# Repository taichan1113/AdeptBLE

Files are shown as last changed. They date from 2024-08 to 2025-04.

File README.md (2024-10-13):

# Excuse

This is alpha version of Ploopy Adept BLE modification.

All necessary files are here but they are still messy.

Document may not reach your satisfaction.

## electronics

Designed by KiCAD and produted by [JLCPCB](https://jlcpcb.com/)

Basically you need XIAO nRF52840 board, PMW3610 optical sensor, omron D2LS-21 mouse switch, 6-pin slide switch and battery.

Other parts are set as below.

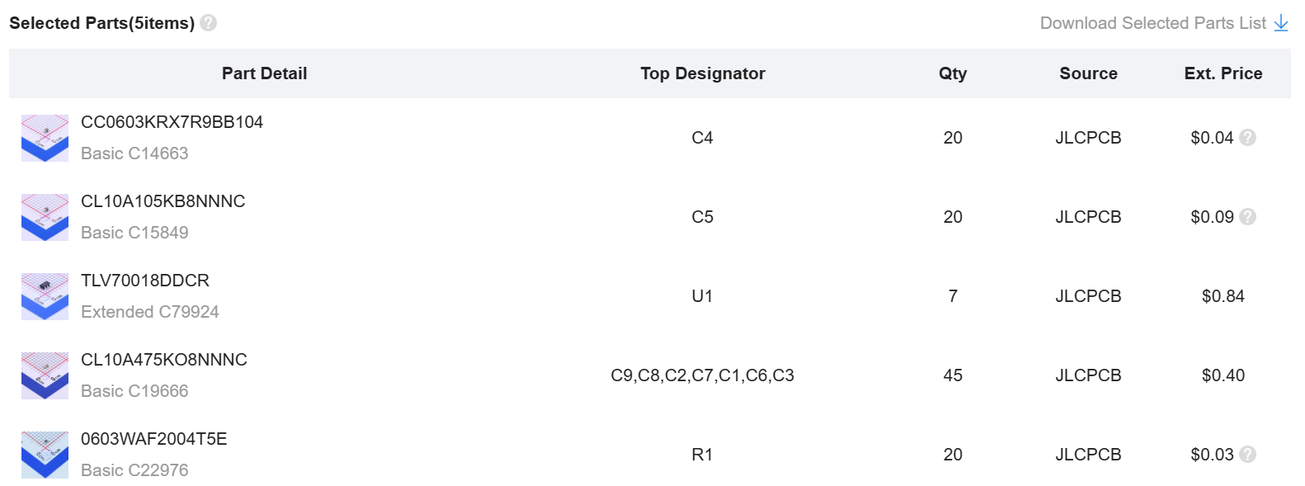
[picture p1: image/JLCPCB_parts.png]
JLCPCB parts JLCPCB Parts


## firmware

Here includes uf2 file built by zmk.

You can find the code [here](https://github.com/taichan1113/mouse-test/tree/main).

## housing

I designed like you only need bottom modified housing additionally.

Note that put the battery wire not to interfere both top and bottom housings.

And you need to cut battery switch so as not to interfere the desk surface.

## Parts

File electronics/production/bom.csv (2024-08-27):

Designator | Footprint | Quantity | Value | LCSC Part #
C1 | 0603 | 1 | 10n | C19666
C2, C7 | 0603 | 2 | 100n | C19666
C3 | 0603 | 1 | 3.3u/16V | C19666
C4 | 0603 | 1 | 0.1u | C14663
C5 | 0603 | 1 | 1u | C15849
C6 | 0603 | 1 | 100n (X7R) | C19666
C8 | 0603 | 1 | 10u (X7R) | C19666
C9 | 0603 | 1 | 10n (X7R) | C19666
J1 | Battery_2pin | 1 | Conn_01x02
J2, J3 | PinHeader_1x06_P2.54mm_Vertical | 2 | Conn_01x06
J4 | PinHeader_1x01_P2.54mm_Vertical | 1 | Conn_01x01
PSW1 | TGSW_MSK-12D19 | 1 | SW_SPDT
R1 | 0603 | 1 | 2M
SW1, SW2, SW3, SW4, SW5, SW6 | SW_D2LS-11_2_OMR | 6 | D2LS-21
U1 | SOT-23-5 | 1 | TCR2EF19 | C146366
U2 | PMW3610 | 1 | PMW3610

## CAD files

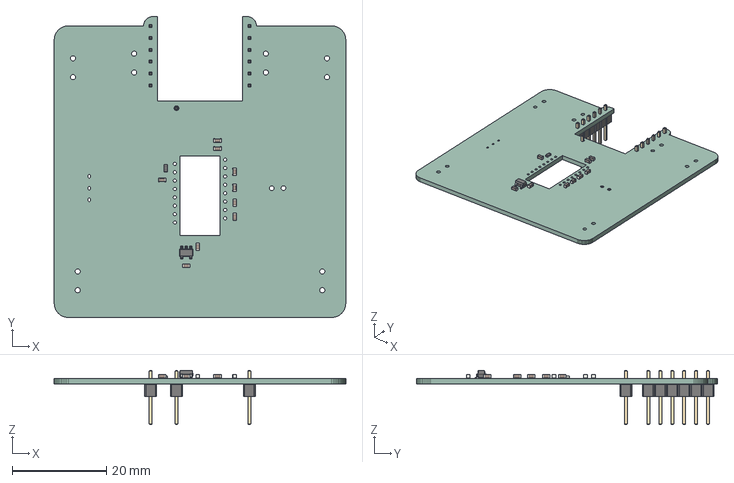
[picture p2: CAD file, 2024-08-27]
electronics/sensor.step
62.0 x 64.0 x 11.5 mm
sensor PCB

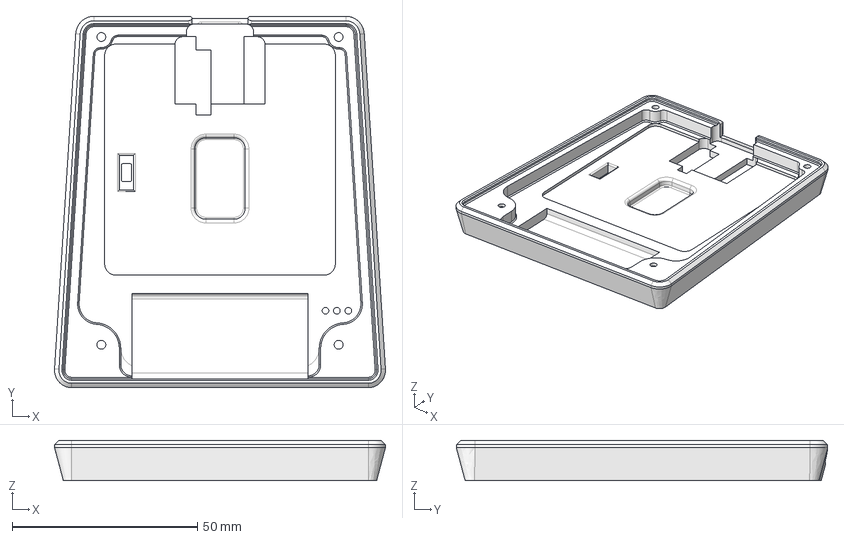
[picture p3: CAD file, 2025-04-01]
housing/AdeptBLE_bottom.step
89.3 x 100.2 x 10.9 mm

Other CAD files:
housing/AdeptBLE_bottom.3mf

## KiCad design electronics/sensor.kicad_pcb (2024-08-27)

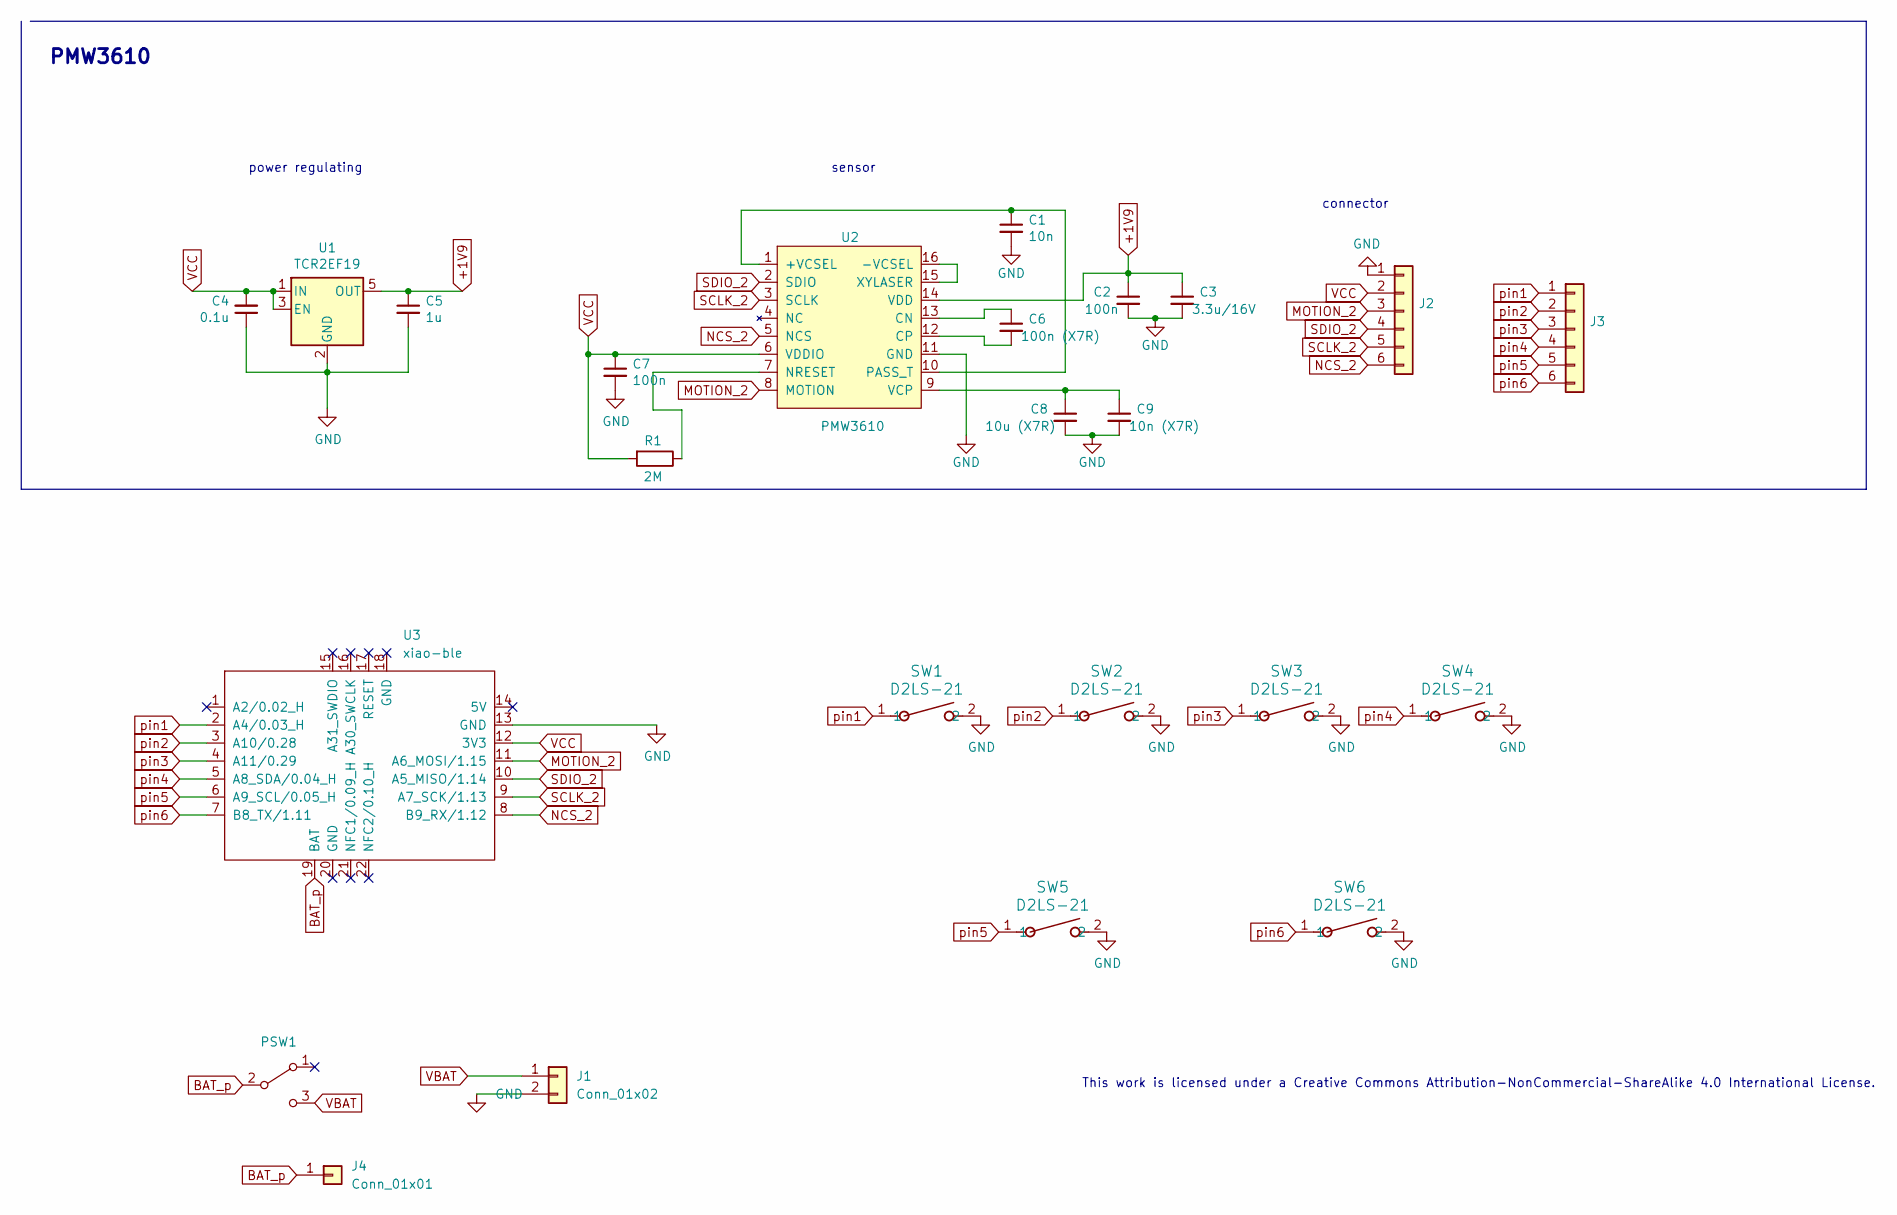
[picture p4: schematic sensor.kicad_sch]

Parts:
C1: 10n; C_0603_1608Metric; LCSC C19666
C2, C7: 100n; C_0603_1608Metric; LCSC C19666
C3: 3.3u/16V; C_0603_1608Metric; LCSC C19666
C4: 0.1u; C_0603_1608Metric; LCSC C14663
C5: 1u; C_0603_1608Metric; LCSC C15849
C6: 100n (X7R); C_0603_1608Metric; LCSC C19666
C8: 10u (X7R); C_0603_1608Metric; LCSC C19666
C9: 10n (X7R); C_0603_1608Metric; LCSC C19666
J1: Conn_01x02; Battery_2pin
J2, J3: Conn_01x06; PinHeader_1x06_P2.54mm_Vertical
J4: Conn_01x01; PinHeader_1x01_P2.54mm_Vertical
PSW1: SW_SPDT; TGSW_MSK-12D19
R1: 2M; R_0603_1608Metric
SW1, SW2, SW3, SW4, SW5, SW6: D2LS-21; SW_D2LS-11_2_OMR
U1: TCR2EF19; SOT-23-5; LCSC C146366
U2: PMW3610
U3: xiao-ble; xiao-ble-tht

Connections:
+1V9: C2.1, C3.1, C5.1, U1.5 (OUT), U2.14 (VDD)
BAT_p: J4.1, PSW1.2 (B), U3.19 (BAT)
GND: C1.2, C2.2, C3.2, C4.1, C5.2, C7.2, C8.2, C9.2, J1.2, J2.1, SW1.2, SW2.2, SW3.2, SW4.2, SW5.2, SW6.2, U1.2 (GND), U2.11 (GND), U3.13 (GND)
MOTION_2: J2.3, U2.8 (MOTION), U3.11 (A6_MOSI/1.15)
NCS_2: J2.6, U2.5 (NCS), U3.8 (B9_RX/1.12)
unnamed: C1.1, U2.1 (+VCSEL), U2.10 (PASS_T)
unnamed: U2.15 (XYLASER), U2.16 (-VCSEL)
unnamed: C6.1, U2.13 (CN)
unnamed: C6.2, U2.12 (CP)
unnamed: R1.1, U2.7 (NRESET)
unnamed: C8.1, C9.1, U2.9 (VCP)
SCLK_2: J2.5, U2.3 (SCLK), U3.9 (A7_SCK/1.13)
SDIO_2: J2.4, U2.2 (SDIO), U3.10 (A5_MISO/1.14)
VBAT: J1.1, PSW1.3 (C)
VCC: C4.2, C7.1, J2.2, R1.2, U1.1 (IN), U1.3 (EN), U2.6 (VDDIO), U3.12 (3V3)
pin1: J3.1, SW1.1, U3.2 (A4/0.03_H)
pin2: J3.2, SW2.1, U3.3 (A10/0.28)
pin3: J3.3, SW3.1, U3.4 (A11/0.29)
pin4: J3.4, SW4.1, U3.5 (A8_SDA/0.04_H)
pin5: J3.5, SW5.1, U3.6 (A9_SCL/0.05_H)
pin6: J3.6, SW6.1, U3.7 (B8_TX/1.11)

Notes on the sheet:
This work is licensed under a Creative Commons Attribution-NonCommercial-ShareAlike 4.0 International License.
sensor
PMW3610
power regulating
connector

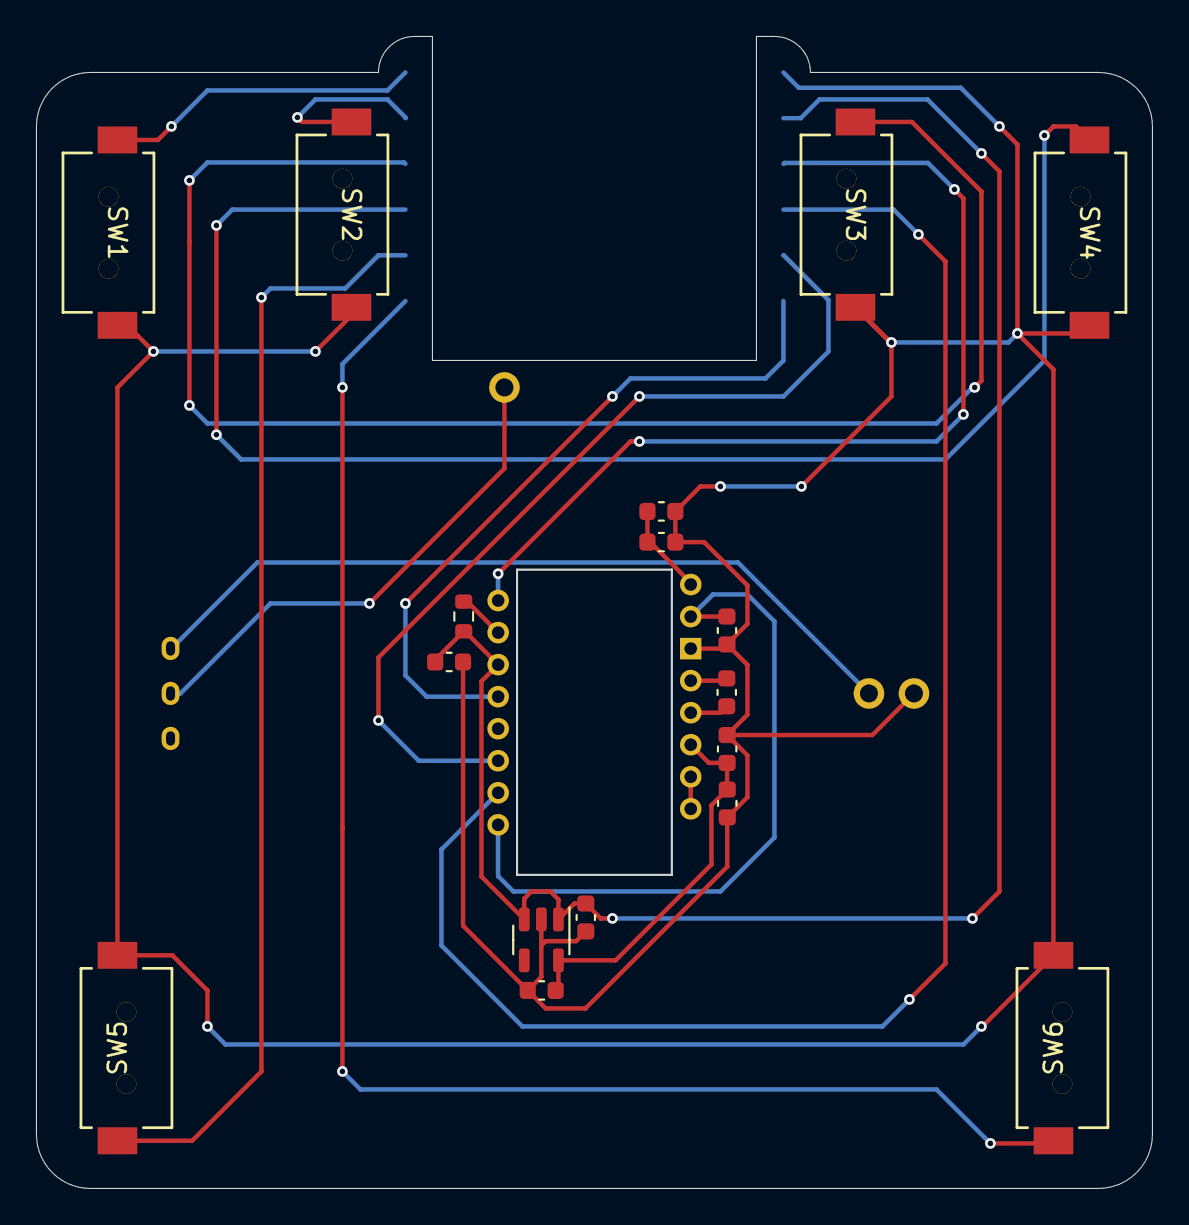
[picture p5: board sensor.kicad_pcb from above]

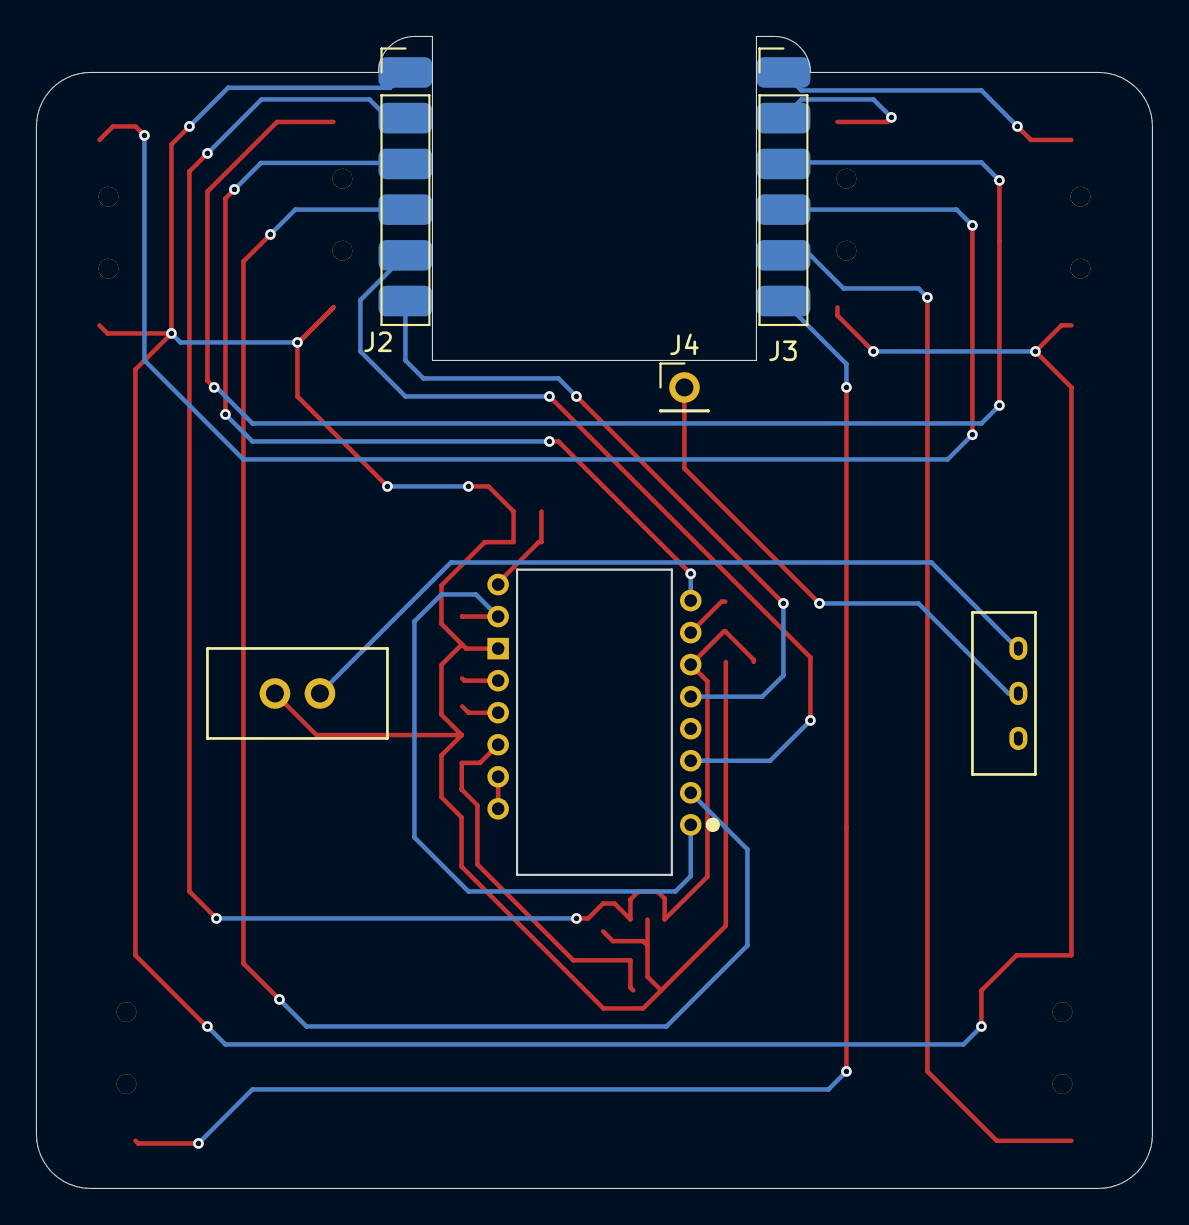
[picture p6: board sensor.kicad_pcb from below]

Board: 2 copper layers, 62.0 x 64.0 mm, 23 parts (6 on the bottom side), 21 nets.

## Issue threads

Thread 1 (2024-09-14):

Requesting Information on PCB Configurations

tottalE, 2024-09-14:
Hi, I found out this repo and really interested to make it but I am not friends with hardwares yet. I've been looking into building some of your hardware.

I have a question regarding our current PCB design.
When ordering a PCB from JLCPCB, I would like to know if there are any specific configurations required, such as number of layers, thickness, etc. Can I just use the same settings as the default Floopy adept?

Again, thank you for our open source and I think this is amazing.

taichan1113, 2024-09-23:
Sorry for my late reply

PCB includes just two layers and its thickness should be as same as original one

And you have to replace some electronic components about optical sensor

I referred these two sites

https://github.com/siderakb/pmw3610-pcb

https://github.com/victorlucachi/charybdis-pmw3610-breakout

tottalE, 2024-09-26:
No worries!
I will try to assemble it.
Can I ask questions later when I get troubled?

Thank you.

taichan1113, 2024-09-28:
Sure
It's bit tricky to assemble PCB and Xiao
But try it

tottalE, 2024-10-09:
Hey!
Can I ask you one thing?
I have some problem for buying TCR2EF19 capacitor.
Can I change it to LT1763 or TLV70018DDCR?

Thank you.

taichan1113, 2024-10-13:
Yes TLV70018DDCR is  what I selected finally

taichan1113, 2024-10-13:
I updated README to make sure what parts I selected

tottalE, 2024-10-15:
Thanks!!!!!

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
this is my order based on your bom. (I ordered almost a month ago.. )
I just ordered based on value.
Should I order new one based on your parts?

taichan1113, 2024-10-15:
I believe it should work if you put U1 parts later

tottalE, 2024-10-17:
Thanks!
I am planning to update readme after my completion for tutorial
Cheers!

tottalE, 2024-10-23:
Hello.
As I started to assemble, I noticed there is tiny gap gap between J1 and K3 and for both, I tried to connect to XIAO by vertical connector but it cannot be connected to each other. Should I just solder it on top or do I need some kind of pin to connect it?

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

Thank you

taichan1113, 2024-10-26:
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

This is how I solder my prototype.
And I also used insert nut to make reassembling easy

ianmarquez, 2025-01-30:
hi @tottalE

just want to ask how did it go building the prototype? looking into building mine as well

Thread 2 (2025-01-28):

Question Regarding your Prototype

ianmarquez, 2025-01-28:
Hi -

First off thank you for creating this prototype looking forward to building it once the PCBs arrive.

I would just like to ask

1. What battery size did you use?
3. What size heatset inserts did you use for your build?

taichan1113, 2025-02-08:
Thank you for your comment

Can you see the PCB files?
You can find suitable size from it

And if you are talking about insert nut I'm using M2 insert nut and it's outside diameter is 3mm

ianmarquez, 2025-02-11:
yeah just saw it!

thanks for your work, looking forward to trying it out once all the materials arrive.

Closed 2025-02-11.

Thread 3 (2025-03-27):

CAD source for Bottom Housing

leclaron, 2025-03-27:
Hi,
Would you be able to share your CAD source for the bottom housing?
I want to modify it for a different battery size.

Closed 2025-04-05.

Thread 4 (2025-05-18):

Options for the top cover

Eloy98, 2025-05-18:
https://github.com/ploopyco/adept-trackball/tree/master/hardware/mechanicals-btu-mod
I printed this cover, and after installing the BTU, the trackball cannot be recognized normally. I would like to ask which cover you used.

taichan1113, 2025-05-18:
I use default cover for roller ball bearing.
But I once tried BTU mod with this BLE mod and I found sensor didn't recognize the ball track depending on its color.
For me, yellow ball worked but white didn't.

I made this bottom cover with compatibility of original one but the optical sensor is difference which I beleive this issue is comming from.

If you want to use both BTU and BLE mod, there will be two choices
 - change the hight of bottom cover to make sensor side close to  / apart from ball
 - change the hole position of BTU to make ball side close to / apart from sensor

Eloy98, 2025-05-18:
I am using a 44mm red trackball. After testing, I found that it was a distance problem. I now adjust the lens upwards and it works fine.

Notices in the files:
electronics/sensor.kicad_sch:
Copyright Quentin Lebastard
